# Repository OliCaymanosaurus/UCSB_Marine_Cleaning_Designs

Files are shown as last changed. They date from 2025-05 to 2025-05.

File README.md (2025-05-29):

# UCSB_Marine_Cleaning_Designs
Work with Washburn Lab

This repository contains the design files, CAD models, prototypes, and documentation for marine instrument cleaning tools I developed in collaboration with the **Washburn Lab** at the University of California, Santa Barbara (UCSB).

My primary focus while interning at this lab was designing underwater hardware systems — including syringe holders, wire brush covers, and other cleaning mechanisms — that can be deployed and tested in marine environments to reduce dive times for maintaince and hasssle. All designs are optimized for 3D printing and underwater durability.

---

## 🛠 What’s Inside

- **3D CAD Models:** STL files for underwater cleaning tools.
- **Design Iterations:** Iterations and prototypes for final designs
- **Prototyping Notes:** Documentation on design decisions, materials, and underwater testing.

---

## 🌊 About the Project

This work is part of my engineering efforts at UCSB’s Washburn Lab, focusing on developing innovative solutions for issues in their marine instruments and RADARs. I aim to create tools that are lightweight, printable, and effective in real-world underwater conditions.

---

## 📂 Repository Structure

/designs → CAD files and models
/iterations → Past versions and design experiments
/docs → Design notes, test results, and specifications

yaml
Copy
Edit

---

## 🤝 Contributors

- Oliver Werkhoven

---

## 🚀 Getting Started

To explore the designs:
1. Clone this repository.
2. Navigate to `/designs` or `/prototypes`.
3. Load CAD files in your preferred modeling software (OnShape, Fusion 360, SolidWorks, FreeCAD, etc.).
4. Follow the `/docs` folder for assembly instructions or material recommendations.

---

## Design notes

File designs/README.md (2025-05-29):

This folder contains the core CAD models and design files for the marine cleaning tools developed during my internship at the Washburn Lab.

Contents:
- **STL files** for 3D printing.
- Subfolders organized by project

**Note:** All files are optimized for underwater use and 3D printing on common FDM printers.

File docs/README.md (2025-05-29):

# Documentation

## 🌊 Background

Oceanographic instruments that measure pH, chlorophyll, and other marine parameters are highly vulnerable to marine growth, which can disrupt data accuracy.  

Currently, two divers are required every two weeks to manually clean these sensors using bleach. The standard method — carrying syringes of bleach in a bag — has proven to be cumbersome, as the syringes often float away and are difficult to keep track of underwater.

---

## 🧪 Syringe Holder Prototypes

### **V1: Initial Design**
- 3D printed circular holder with 7 holes for syringes and a dozen smaller holes for zip ties.
- **Issue:** Cold water caused the syringes to shrink and escape the holder. Divers had to hold the contraption sideways to prevent the syringes from floating out.

---

### **V2: Tighter Fit**
- Increased capacity to 10 syringe slots with smaller holes for a tighter fit and better retention.
- **Issue:** Syringes still floated out in cold water. Overlapping syringe tabs led to jamming in the center.

---

### **V3: Tapered Fit**
- Fixed spacing of holes.
- Tapered holes drafted inward for a tighter fit at the bottom, while still allowing easy insertion.
- **Issue:** Circular shape was awkward to hold underwater. Required a second diver to hold while dispensing bleach.

---

### **V4: Linear Handle Design**
- Shifted to a linear shape with a handle.
- Can be set directly on the instrument caging.
- **Result:** Reduced cleaning time, allowing the task to be performed by a single diver.

---

## ⚙️ Automation Concepts

### Existing Setup
The instruments already use periodic **air blasts** to reduce buildup, but still require bleach treatments every two weeks.

---

### **Proposed Solution: Integrated Bleach Dosing**
We are testing a **passive bleach delivery system** that leverages the existing air pathway:
- **Mechanism:** Solid bleach capsules are placed within a segment of tubing connected to the air line.
- Each air pulse partially dissolves a capsule, pushing bleach-laced water into the instrument.
- As water naturally refills the tubing after the blast, the next air cycle continues dissolving the capsule incrementally.

---

### System Details
- The air pump turns on once every 24 hours.
- Total: 8 air blasts.
- The first 7 blasts: ~1 second each.
- The final blast: ~10 seconds.
- This cycle pushes air through the reservoir, including the stagnant water, and flows it through the CTD plumbing.

> **Note:** It remains unclear if the CTD pump can also pull some of the reservoir water into the CTD plumbing.

---

## 📌 Summary

These prototypes and automation efforts aim to reduce diver time, improve safety, and maintain high-quality instrument readings over long-term deployments.

---

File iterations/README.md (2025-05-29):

This folder holds past design versions, concept models, and experimental prototypes.

Contents:
- Early-stage CAD designs.
- Abandoned or alternative design paths.
- Notes on what worked, what didn’t, and why certain designs were improved or replaced.

This archive is meant to document the design evolution and preserve useful ideas for future reference.

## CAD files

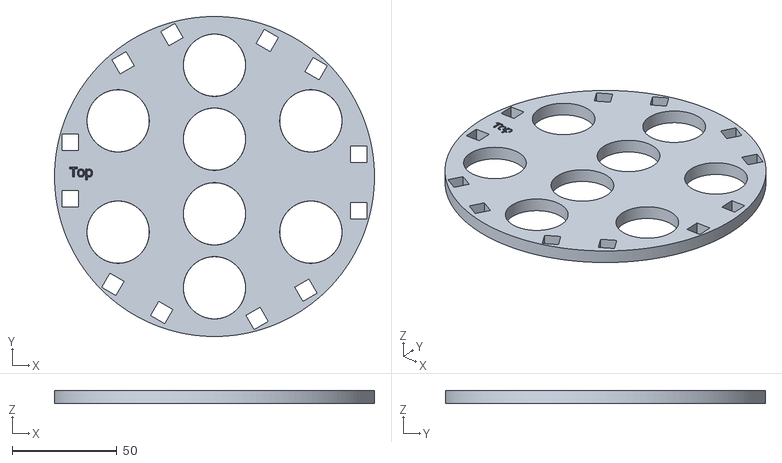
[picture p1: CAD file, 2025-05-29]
designs/Syringe_Holder_Attachment_CIRCLE.stl
152.4 x 152.4 x 6.35

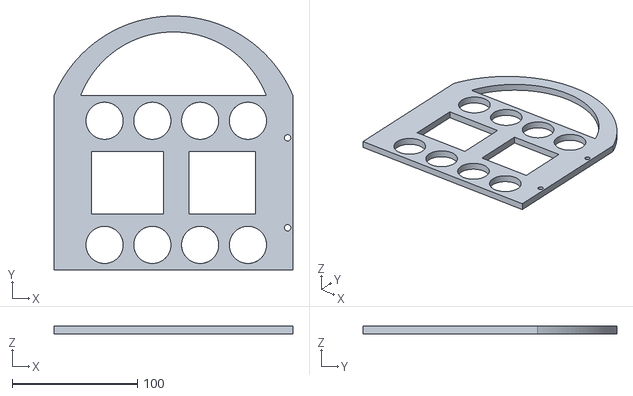
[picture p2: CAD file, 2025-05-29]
designs/Syringe_Holder_Attachment_LINE.stl
190.5 x 202.4 x 6.35

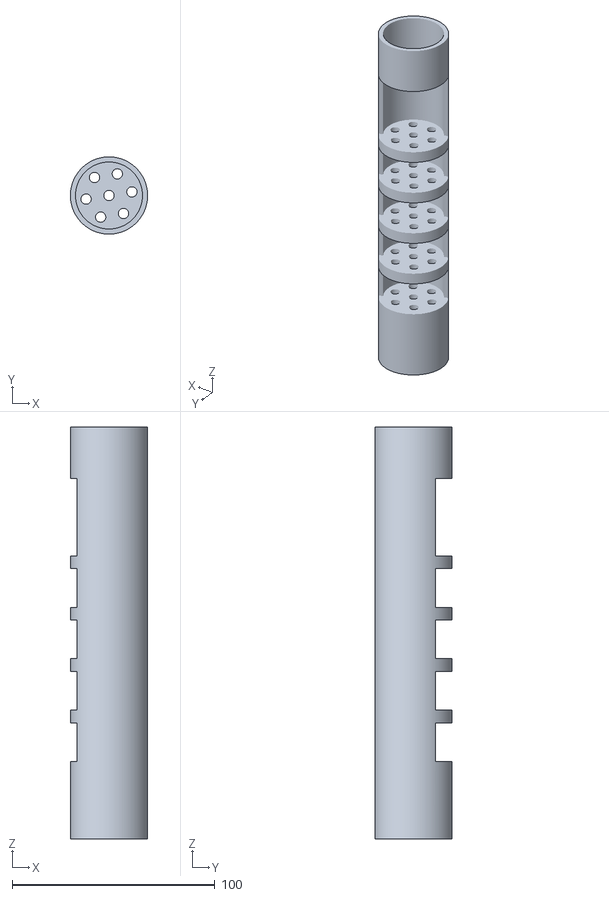
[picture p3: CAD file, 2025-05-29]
designs/CapsuleHolder.stl
38.1 x 38.1 x 203.2
